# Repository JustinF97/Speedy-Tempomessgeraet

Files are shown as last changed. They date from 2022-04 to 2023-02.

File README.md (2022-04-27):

# Speedy-Tempomessgerät

[Justin Frommberger](https://github.com/JustinF97)

[Jonas Gerken](https://github.com/JonasGerken)

| Aufgabe | Link | 
| --- | --- |
| Projekt |[Link](https://github.com/)|  
| Ausarbeitung  |[Link](https://github.com/)|

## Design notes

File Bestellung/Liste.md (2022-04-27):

Material            | Name                        |Menge          | ❌ ✅
-----------         | ----------                  | ---------     | -------
Arduino             | Arduino Uno                 | 1x            |  ❌ 
Widerstände         | 220 & 60 Ohm                | 1x            |  ❌
RGB LED-Streifen    | WS2812B (60 LEDs/Meter)     | Ca. 5 Meter   |  ❌
Spannungsversorgung | Steckernetzteil  5V, 3A     | 1x            |  ❌
Gehäuse             | MDF-Platten 100/70/? Cm     | 3x            |  ❌
Kabel               | 0,5 / 0,75mm^2              | 3 Meter       |  ❌

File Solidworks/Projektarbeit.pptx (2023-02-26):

## Projektarbeit Speedy-Tempomessgerät

Von Jonas gerken und Justin Frommberger

## Thema

- Geschwindigkeit Messung von Autos
- Sicherheit von Personen
- Warnung bei zu schnellem fahren

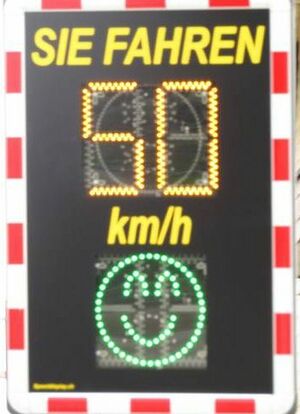
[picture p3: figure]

## Aufgabenstellung

- Ein System entwerfen
- Materialbeschaffung
- Zusammenbau des Projektes
- Anforderungen erfüllen
- Dokumentation
- Präsentation

## Anforderungen

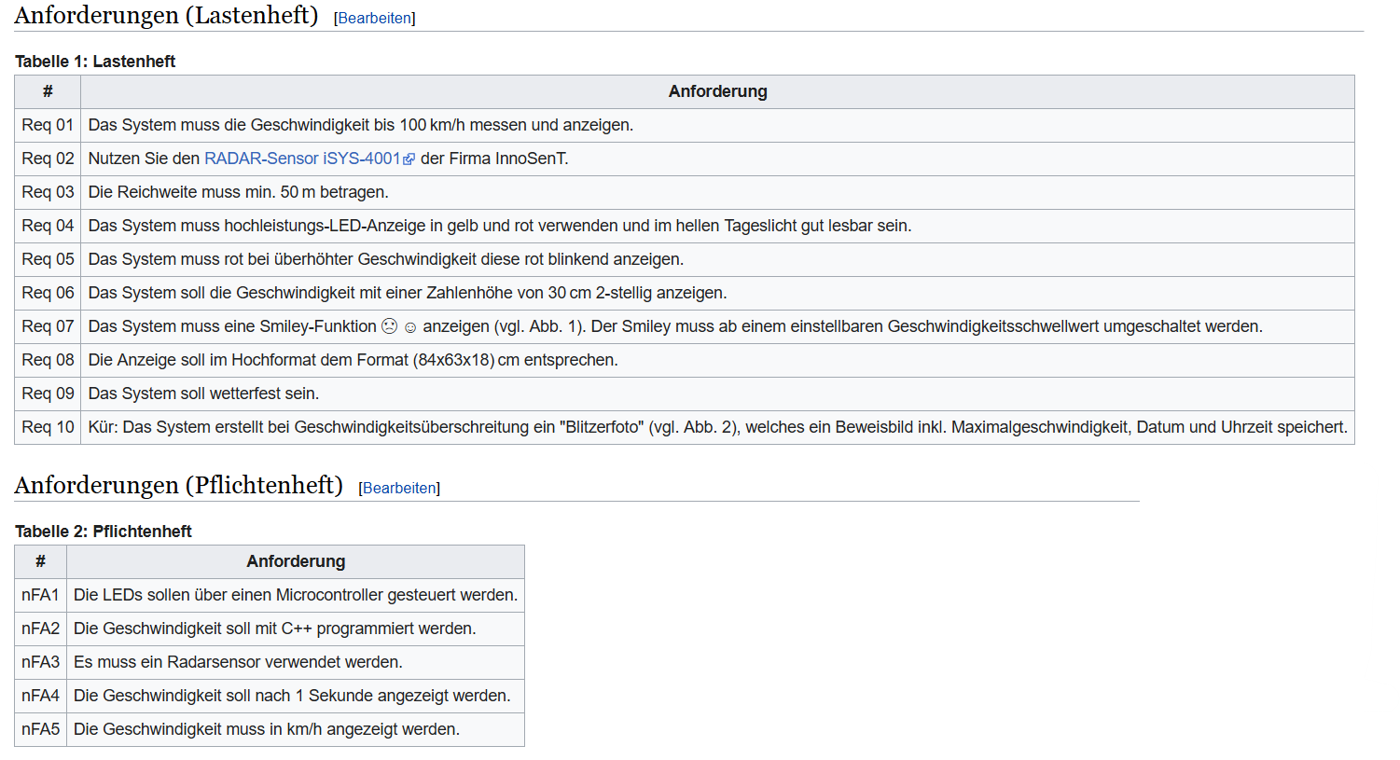
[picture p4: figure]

## Projektplan

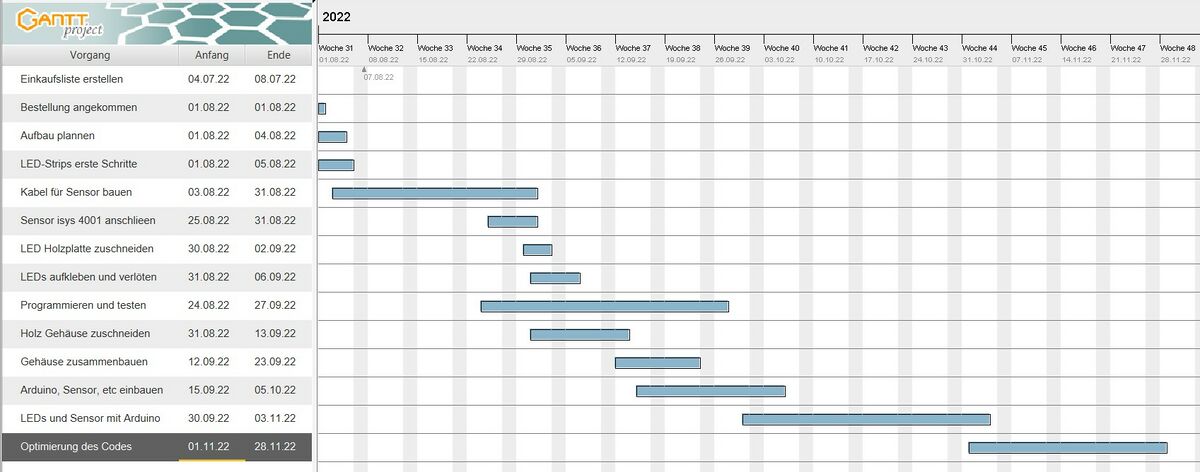
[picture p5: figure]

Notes: Jonas

## BOM (Bill of material)

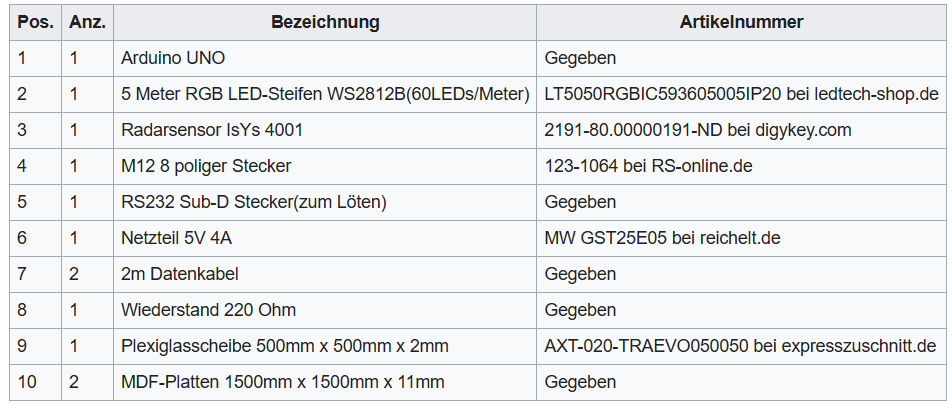
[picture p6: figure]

## Systementwurf

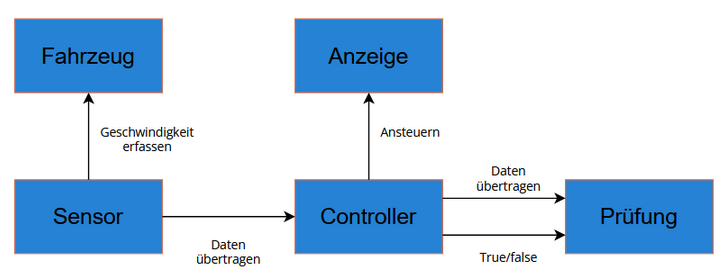
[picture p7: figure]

## Zeichnungsentwurf

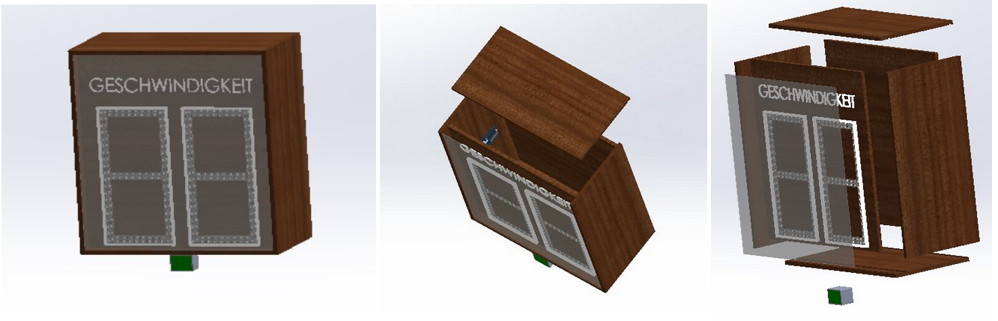
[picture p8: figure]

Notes: Jonas

## Elektronik

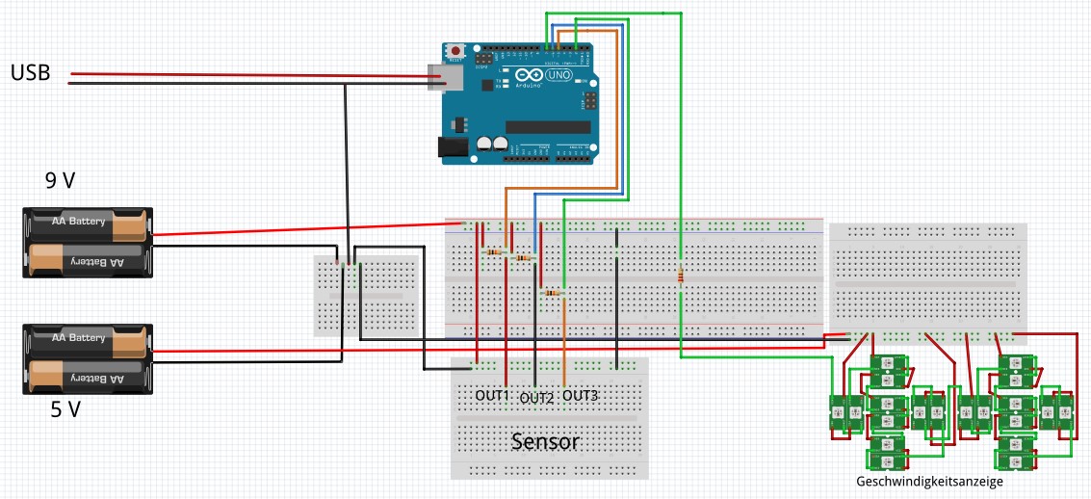
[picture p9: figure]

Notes: Jonas

## LED-Anzeige

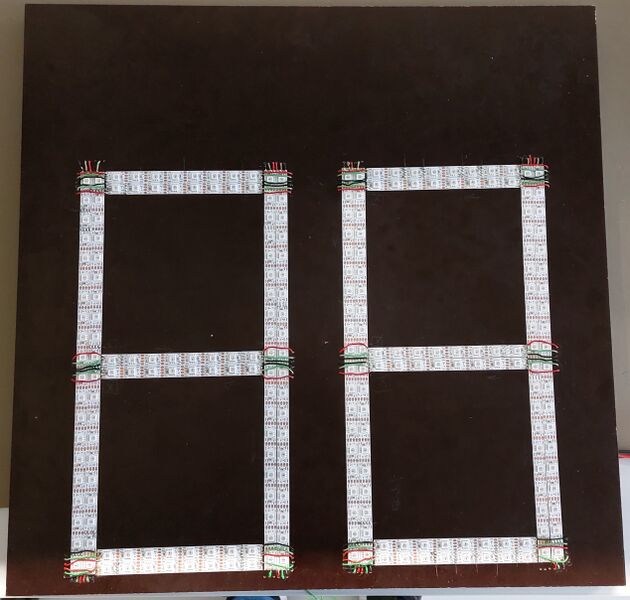
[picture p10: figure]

## Sensor GUI

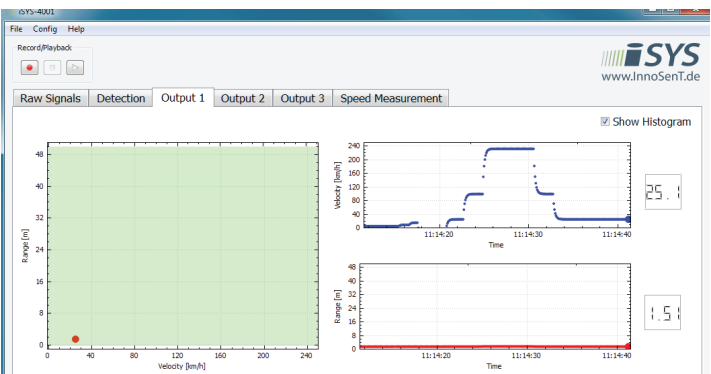
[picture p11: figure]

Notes: Jonas

## Sensor GUI Einstellungen

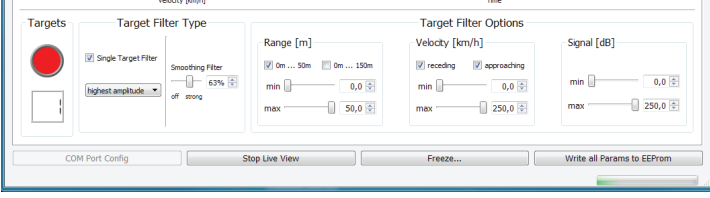
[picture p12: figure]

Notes: Jonas

## Output Konfiguration

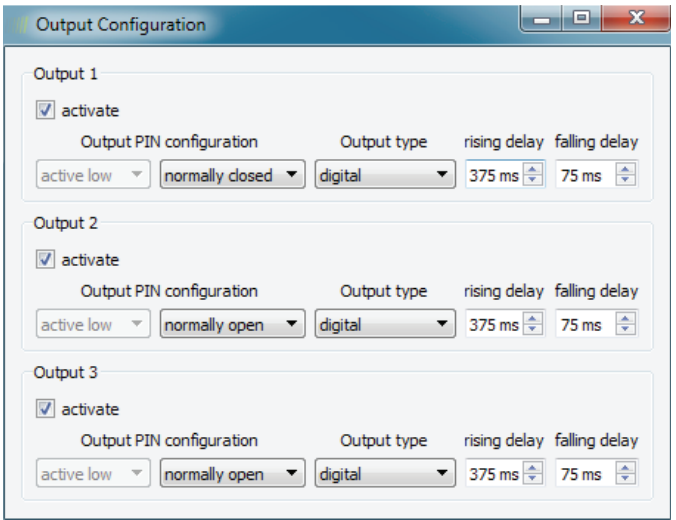
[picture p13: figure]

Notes: Jonas

## PWM

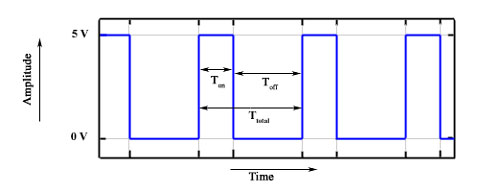
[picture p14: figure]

## Programmierung (Farbe)

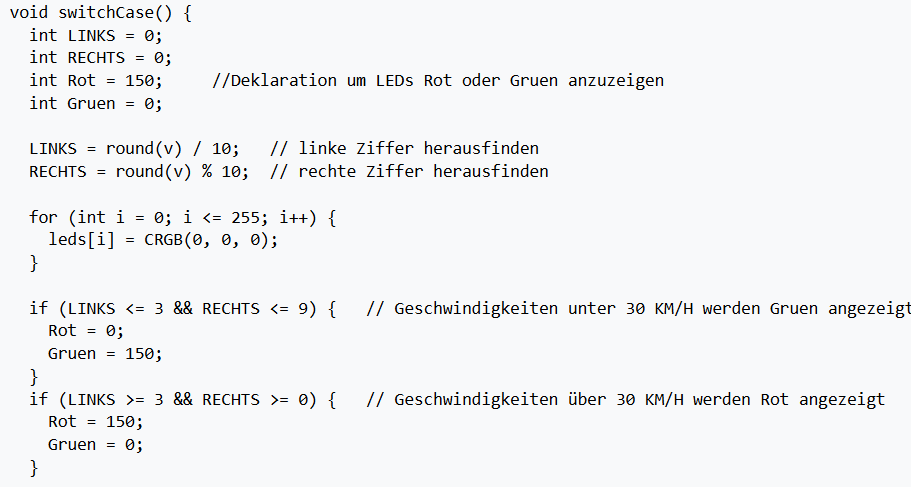
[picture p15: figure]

## Programmierung (Zahlen)

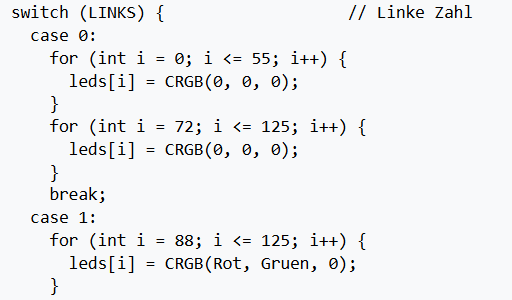
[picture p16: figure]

## Programmierung (Sensor)

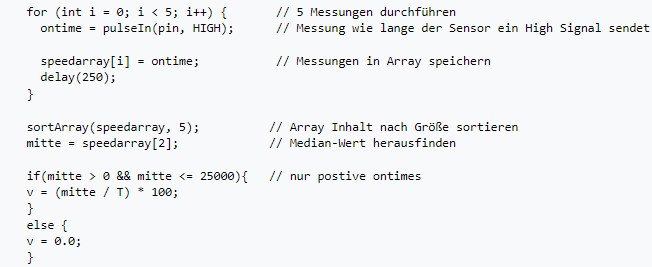
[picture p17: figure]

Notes: Jonas

## Live Präsentation

## Zusammenfassung

- Folgende Kompetenzen wurden erlernt:
- Projektplanung und Zeitmanagement
- CAD Konstruktion für 3D Druck
- 3D Druck
- Löten
- Ansteuerung von WS2812 LEDs
- Bau eines Kabels

## Ergebnis

- - Smiley Gesicht nicht eingebaut
- - Km/h nicht auf dem Schild beschriftet
- - Kleineres Gehäuse
- - Sensor funktioniert nicht einwandfrei
+ LED‘s zeigen die gewünschte Zahl an
+ Gehäuse ist stabil und transportabel
+ Autos können erfasst werden
+ Geschwindigkeit wird zur Anzeige übertragen

## Ausblick

- Smiley integrieren
- Sensor optimieren
- System durch Kamera erweitern

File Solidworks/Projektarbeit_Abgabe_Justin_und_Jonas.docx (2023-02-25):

Sommersemester 2022-
Wintersemester 2022/23

Praxissemester:

01.08.22 – 28.02.2023

Hochschule Hamm-Lippstadt

Praxissemester

Betreuer/in: Prof. Schneider

- Projektarbeit-

Einleitung

Der Schulweg von Kindern ist nicht sehr sicher. Durch Geschwindigkeitsmessungen des ADAC vor 25 Schulen in zehn Bundesländern wurden häufig Fahrer mit zu hohen Geschwindigkeiten gemessen. Die zulässige Höchstgeschwindigkeit von 30 km/h wurde von mehr als 60 Prozent der Autofahrer überschritten. Von insgesamt 43 828 Messungen, waren 26 329 zu schnell unterwegs. Vor einer Grundschule in Hamburg wurde ein Rekordwert von 96 km/h bei vorgeschriebenen 30km/h gemessen.

Um die Autofahrer abzuschrecken, können sogenannte Tempomessgeräte helfen.
Diese messen die Geschwindigkeit und zeigen diese über eine Anzeige dem vorbeifahrenden Fahrer. Zudem wird oft auch noch mit einem Smiley signalisiert, ob der Fahrer zu schnell fährt oder ob er sich an die vorgegebene Geschwindigkeit hält.

Aufgabenstellung

Die Aufgabe des Projektes war es, ein solches Tempomessgerät mit einem Radarsensor und einer LED-Anzeige, welche die Geschwindigkeit in km/h anzeigt, zu entwickeln.

Anforderungen







Projektplan (Justin Frommberger und Jonas Gerken)



BOM (Justin Frommberger und Jonas Gerken)

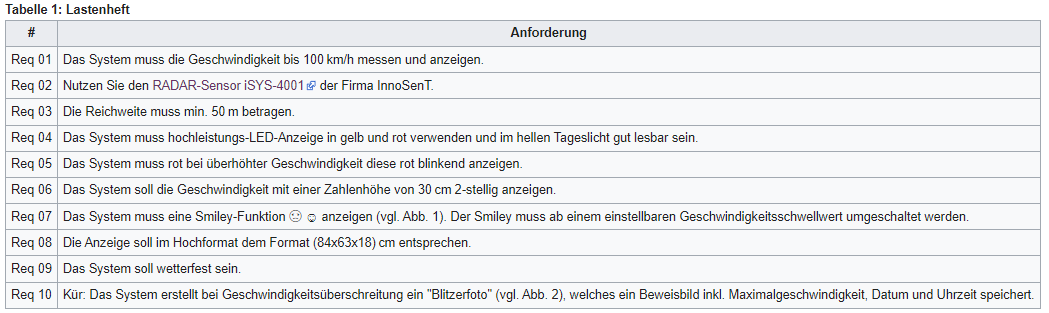
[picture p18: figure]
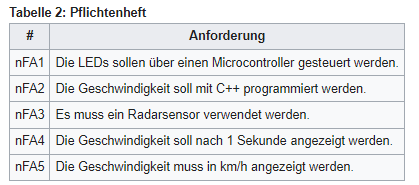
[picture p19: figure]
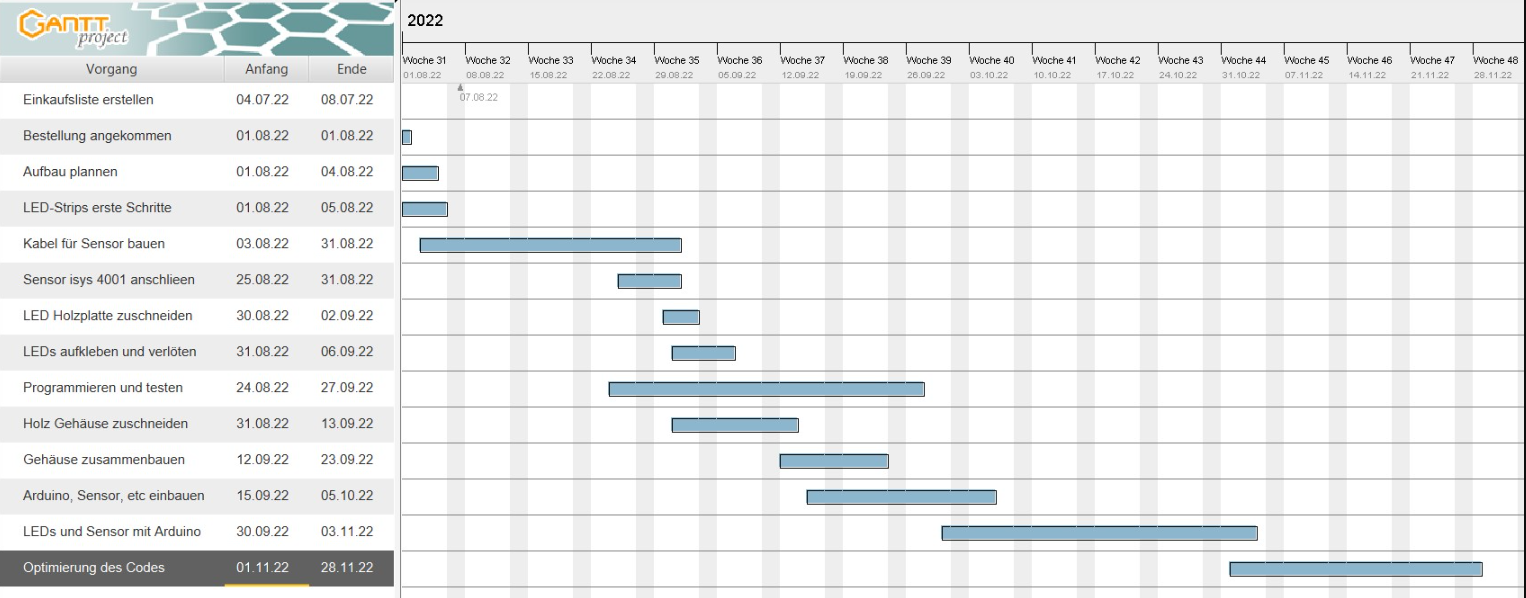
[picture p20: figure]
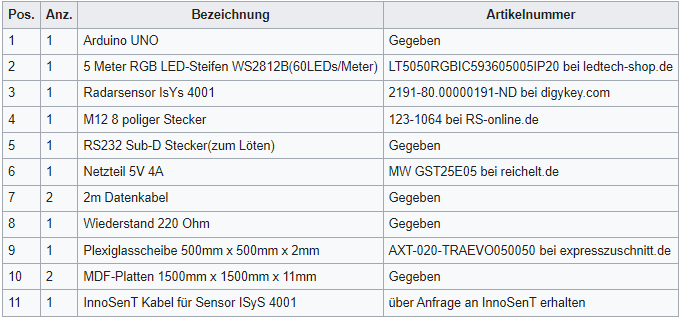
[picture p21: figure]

Funktionaler Systementwurf (Justin Frommberger)

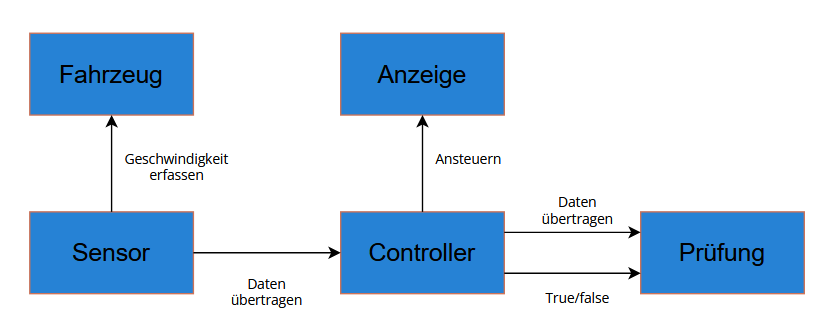
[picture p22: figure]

Abb. 1 Funktionaler Systementwurf

In Abb. 1 wird gezeigt, wie die Komponenten verbunden sind.
Der Sensor erfasst die Geschwindigkeit des Fahrzeugs und übergibt diese dem Microcontroller. Mit dem Mikrocontroller werden die Daten berechnet, die er vom Sensor empfängt. Die berechneten Werten werden dann auf der Segmentanzeige dargestellt.

Technischer Systementwurf (Jonas Gerken)


Abb. 2 Technischer Systementwurf

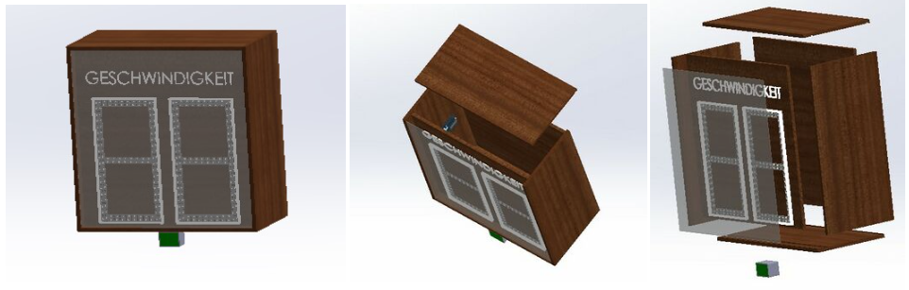
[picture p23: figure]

Die Abbildung 2 zeigt den technischen Systementwurf des Tempomessgerätes als CAD-Modell.

Radarsensor Isys 4001 (Jonas Gerken)

Der Kabelanschluss ist in Abb. 3 grafisch dargestellt.

Dargestellt ist der Female 8-polige Stecker, der mit dem Geschwindigkeitssensor verbunden wird. Das andere Ende des Kabels wird aufgeteilt in eine RS232-Schnittstelle und einem Stecker zur Verbindung mit dem Mikrocontroller der auch die Spannungsversorgung für den Sensor bereitstellt. Die RS232-Schnittstelle wird mit dem Computer verbunden zur Übertragung der Daten.

Abb. 3: Sensoranschluss

Um das Kabel anzuschließen, werden zwei Datenkabel mit Abschirmung benötigt. Das Kabel muss eine Abschirmung haben, um Störsignale zu vermeiden.

Für den RS232-Connector muss ein Kabel an einen Sub-D Stecke mit lötkontakten gelötet werden (Tabelle 1).

Wichtig ist es, die einzelnen Adern mit einem kleinen Schrumpfschlauch zu versehen, damit die Aderisolierung beim Löten nicht beschädigt wird. Das zweite Kabel ist für die Ausgänge Out1, Out2, Out3, genauso wie die Stromversorgung und der Ground.

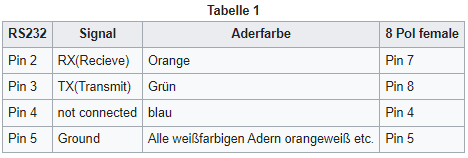
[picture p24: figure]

Für das zweite Kabel, welches für die Datenoutputs und die Stromversorgung verwendet wird, sieht die Pin-Belegungen wie folgt aus. (Tabelle 2)



Da der Sensor mit dem selbst gebauten Kabel nach mehreren Überprüfungen der Verbindungen nicht mit dem GUI-Programm verbunden werden konnte, wurde ein Kabel von der Firma InnoSenT angefragt. Mit diesem Kabel war es dann möglich, den Sensor mit dem GUI zu verbinden und zu konfigurieren.

Sensormessung

Damit ein PWM-Signal vom Sensor gesendet wird, muss zunächst ein Pull-up Widerstand (10kOHM) wie in Abb. 4 gezeigt, zwischen den Outputs geschaltet werden. Bei dem Anschluss an den Arduino muss beachtet werden, dass die Ausgänge OUT 1-3 an die PWM-Schnittstellen angeschlossen werden.


Abb. 4 OUT-Anschlüsse/Verkabelung

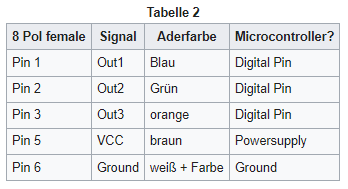
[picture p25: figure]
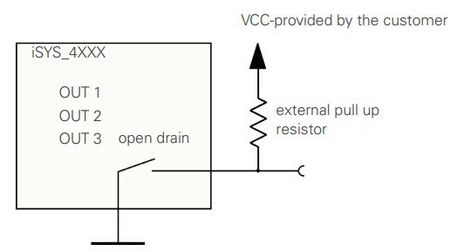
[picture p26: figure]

Das Signal kann nach der Verkabelung über ein Oszilloskop angezeigt werden. (Abb. 5)
Das obere PWM-Signal ist die Entfernung und das untere die Geschwindigkeit.


Abb. 5 PWM-Signal


Der Sensor sendet die PWM-Werte an den Arduino. Mit dem Arduino Befehl pulseIn(pin, HIGH), kann das Signal ausgelesen werden.

Mit den folgenden Formeln (Abb. 6) wird aus einer abgelesenen Geschwindigkeit das DC und folgend das „Ton“ berechnet.
Der Sensor sendet Ton-Werte an den Arduino und dieser muss in eine Geschwindigkeit umgerechnet werden.
Dazu muss die obere Formel nach km/h umgestellt werden und die untere Formel nach DC.
Rechts sind die umgestellten Formeln aufgezeigt, um die Geschwindigkeit zu berechnen.

DC=(6,275)/25⋅100

v=(25*100)/100 Abb. 6 Duty Cycle Formel

LED-Seven-Segment Aufbau und Verlötung (Justin Frommberger)

Der Erste Schritt ist, für die LED-Seven-Segmente eine Holzplatte auf 500 mm x 500 mm zuzuschneiden.
Auf dieser Holzplatte werden dann die LED-Stripes aufgeklebt.

Wir haben uns für die Seven-Segmente anzeige entschieden.

Diese LED-Strips haben wir doppelt nebeneinander geklebt, damit die angezeigte Geschwindigkeit später auf der Straße besser zu lesen ist.

Dazu wurden 8 Strips von einer Länge von 20 LEDs und 12 Strips von einer Länge von 8 LEDs zugeschnitten und angeklebt.


Abb. 7 LEDs auf Holzplatte

Beim Aufkleben ist es wichtig, die LEDs richtig herum aufzukleben.

Drauf geachtet werden muss, dass man mit der Kennzeichnung Strips "Di" für Digital In beginnen muss.

Der erste Strip wurde von oben nach unten geklebt, der Stripe rechts daneben von unten nach oben um die Reihenfolge einzuhalten.

So müssen unten später nur 3 kurze Kabel angelötet werden.

Von links außen und rechts außen wurden 50 mm und von dem unteren Rand wurden 15 mm Platz bis zu den LED-Stripes gelassen.

Abb. 7 zeigt die fertige Segmentanzeige.


Abb. 8: Verkabelung

Bei einer so großen Anzahl an LEDs ist es notwendig, die LEDs an mehreren Stellen mit der Stromquelle zu verbinden.

Dazu wurden, wie in Abb. 8 zusehen ist ein rotes und ein schwarzes 4 mm² Kabel an eine Europlatine gelötet, welche dann die Hauptstromversorgung darstellt.

Die Seven-Segmentanzeige wurde dafür jeweils in drei Abschnitte unterteilt.
Das Seven Segment wurde wie folgt aufgeteilt:
- die linken senkrechten LEDs
- die rechten senkrechten LEDs
- die waagerechten LEDs


Auf der Holzplatte wurden an jeder Ecke 3 Löcher gebohrt, um die Kabel zur Rückseite durchzuführen und dort zu verdrahten.

Für die Verbindungen zwischen den Strips, wurde ein 0,5 mm² Kabel in zwei verschiedenen Farben: Rot (Strom), Schwarz (Erde), Grün (Daten) zugeschnitten und verlötet.

Das Datenkabel wird nicht in Reihen aufgeteilt, denn alle LEDs müssen zur Programmierung in Reihe angeschlossen werden. So kann später mit Variablen jede einzelne LED angesteuert werden.

Die Abschnitte werden jeweils an die Europlatine angelötet, wie auf dem Bild zu sehen ist. (Abb. 8)

LED Dimmung (Jonas Gerken)

Um die Autofahrer mit den LED‘s nicht zu blenden, haben wir uns überlegt, eine Abdeckung mit dem 3D-Drucker zu entwerfen um das Licht zu dimmen. Die einzelnen Bauteile für die Abdeckung wurden mit SolidWorks gezeichnet und in eine STL Datei umgewandelt. Die Einzelteile die mit dem 3D-Drucker gedruckt wurden, haben wir anschließend auf die Holzplatte über die LED‘s festgeklebt.

In Abb. 9 ist dann das Ergebnis der fertigen Abdeckung zusehen.


Abb. 9 LED-Abdeckung


Gehäuse (Justin Frommberger)

Für das Gehäuse wurden drei 11 mm dicke Holzplatten auf 250 mm * 500 mm zugeschnitten. Eine von den Holzplatten wird mit drei Nuten versehen, die Nuten sind zur befestigen der LED-Platte, der Plexiglasscheibe und der Rückwand.


Mit der zweiten und dritten Platte wird die Außenwand befestigt. Die Platte für die Rückwand wird aus einer 11 mm dicken Holzplatte auf 500 mm * 500 mm zugeschnitten. Zudem muss auch die Plexiglasscheibe auf 500 mm * 500 mm zugeschnitten werden, um in die dafür vorgesehene Halterung zu passen. Am Ende schnitten wir die letzte Platte auf 500 mm * 500 mm und klebten auf diese Platte, die 7 Segment LED Pixelstreifen.

Wir montierten alle Teile des Gehäuses zusammen und befestigten diese zusätzlich mit Schrauben für einen besseren Halt.

Der fertige Aufbau ist in Abb. 10 zusehen.


Abb. 10 Gehäuse


Elektronik (Jonas Gerken)

Die Abb. 11 zeigt die Elektrische Schaltung.


Abb. 11: Schaltung


Stromquellen:

- Radarsensor: 5 bis 30 Volt (in Abb. 7 links)
- LED-Geschwindigkeitsanzeige: 5 Volt (in Abb. 7 rechts)

Arduino Uno:

- Digital Pin 3, 5, 6: OUT1, OUT2, OUT3 des Radarsensors
- Digital Pin 7: Digital der Geschwindigkeitsanzeige

Radarsensor:

- OUT1, OUT2, und OUT3 mit einem PULL-UP Widerstand verbunden

LED-Geschwindigkeitsanzeige:

- Senkrechten LED-Streifen jeweils links und rechts mit der Stromquelle verbunden
- die mittleren LED-Streifen jeweils links und rechts mit der Stromquelle verbunden

Programmierung

Farbe der LEDs (Justin Frommberger)

Abb. 12 LED-Programmierung (Farbe)


Zahlen Anzeige (Justin Frommberger)


Abb. 13 Zahlen Anzeige


Um die Zahlen auf dem Display anzuzeigen, wurde ein Switch Case programmiert, um die benötigten LEDs einzuschalten. Wie im Beispiel Case 0, werden alle LEDS von 0 bis 55 und von 72 bis 125 eingeschaltet.


Sensor (Jonas Gerken)

Abb. 14 Sensor Programmierung


Ergebnis (Justin Frommberger und Jonas Gerken)

Fast alle Anforderungen des Projektes konnten erfüllt werden. Wir unterschätzten, dass die LED‘s eine Menge an Strom benötigen (aktueller Stand 10A), so mussten wir bei unserem Projekt LED‘s einsparen und beschlossen das Smiley Gesicht nicht einzubauen.

Um trotzdem die gewünschte Aufgabe zu erfüllen, überlegten wir uns, dass wir die nicht überschrittene Geschwindigkeit Grün anzeigen lassen.

Die zu hohe Geschwindigkeit stellen wir in roter Farbe dar. Zudem haben wir uns für ein kleineres Format des Schildes entschieden, um unser Projekt besser transportieren zu können. Auch haben wir uns gegen einen Schriftzug vom km/h entschieden, um die Zahlen möglichst groß und sichtbar für die Fahrer zu gestalten. Leider haben wir festgestellt, dass der vorhandene Radarsensor Isys 4001 eine Störung hat und keine konstanten Werte zurückliefert, dieses führt bei der Anzeige zu ungenauen Werten.

Alle anderen oben aufgelisteten Anforderungen konnten wir erfüllen.

Zusammenfassung (Justin Frommberger und Jonas Gerken)

Lessons learned

Das Team hat die folgenden Kompetenzen erlernt:

- Projektplanung und Zeitmanagement
- CAD-Konstruktion für 3D Druck
- 3D Druck
- Löten
- Ansteuerung von WS2812 LEDs
- Bau eines Kabels

Besondere Herausforderungen

Die erste Herausforderung bei unserem Projekt „Speed-Tempomessgerät“, stellte sich direkt am Anfang bei der Materialbeschaffung. Das Problem war es, das alle Materialien, die für das Projekt benötigt werden zu beschaffen. Wir stellten fest, dass bei dem vorhandenen Radarsensor der Hochschule das Kabel zur Strom- und Datenversorgung fehlte. Weil das Kabel kein Standardkabel war, informierten wir uns bei dem Hersteller des Sensors wie das Kabel aufgebaut ist und ließen uns das dazugehörige Datenblatt schicken. Um das Kabel selbst anzufertigen, bestellten wir dafür einen RS232 Sub-D Stecker und einen M12 8 poligen Stecker. Das Herstellen des Kabels konnte nach langem ausprobieren und telefonischem Austausch mit der Herstellerfirma nicht abgeschlossen werden. Folgend fragten wir die Firma, ob sie uns ein Kabel zuschicken könnten. Freundlicherweise ließen sie uns ein Kabel kostenlos zukommen, um unser Problem zu lösen.

Die nächste Herausforderung war es, herauszufinden, wie groß die Netzteile seien müssen, um unser komplettes Projekt mit Strom zu versorgen. So recherchierten wir in den Datenblättern des Sensors und der RGBs, wie groß die Netzteile sein müssen. Später stellte sich heraus beim Anschließen der RGB-Kette, dass die LED‘s viel mehr Strom in Reihenschaltung benötigten als wir berechnet hatten (über 20A). Folgend beschlossen wir unsere Schaltung um zulöten, wir setzten die Stromversorgung mittig und teilten diese in 4 Reihenschaltungen auf. Wir verringerten den benötigten Stromverbrauch auf ungefähr 10A. Zusätzlich verzichteten wir auf weitere RGBs für das Smiley, um Strom zu sparen und ein transportables Netzteil nutzen zu können.

Eine weitere Herausforderung im Projekt war die Ansteuerung der einzelnen RBGs, da diese teilweise zusammengeschaltet sind und beim Ansteuern einer RBG zwei Stück eingeschaltet werden. Nach mehrfachen neu Löten konnte der Fehler nicht gefunden werden.

Daraufhin haben wir uns eine neue Schaltung (Abb.8) entwickelt, mit der wir unsere Schaltung umsetzen konnten.

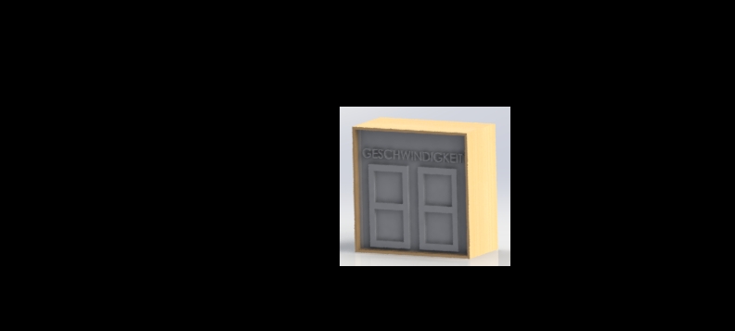
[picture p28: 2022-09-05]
Solidworks/Solidworks_Projektarbeit/Bilder/Tempomessgerät_Schild.JPG

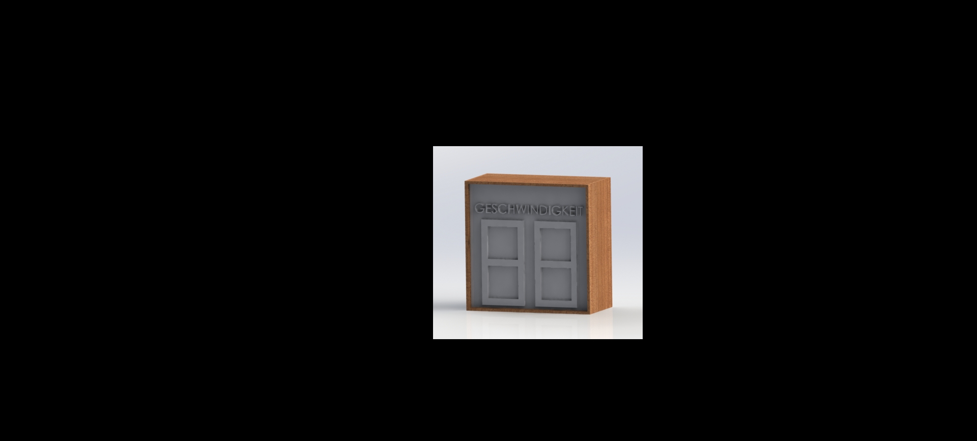
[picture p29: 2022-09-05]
Solidworks/Solidworks_Projektarbeit/Bilder/Rendering Schild2.JPG

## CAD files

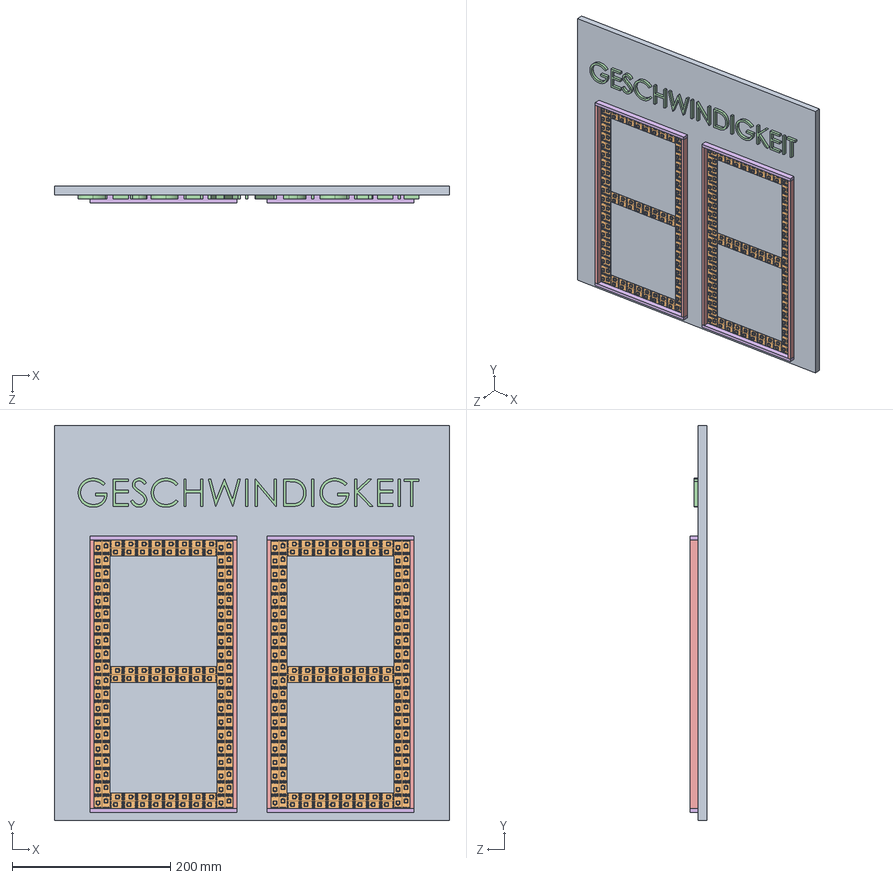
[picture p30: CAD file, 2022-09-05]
Solidworks/Solidworks_Projektarbeit/LED_Platte_Baugruppe.SLDASM
500.0 x 500.0 x 21.0 mm
LED-PLatte 2
LED-Strip x 256
Kumpferplätchen x 2048
SchildSchrift
Lichtschirmlang x 4
Schirmmittellang x 4

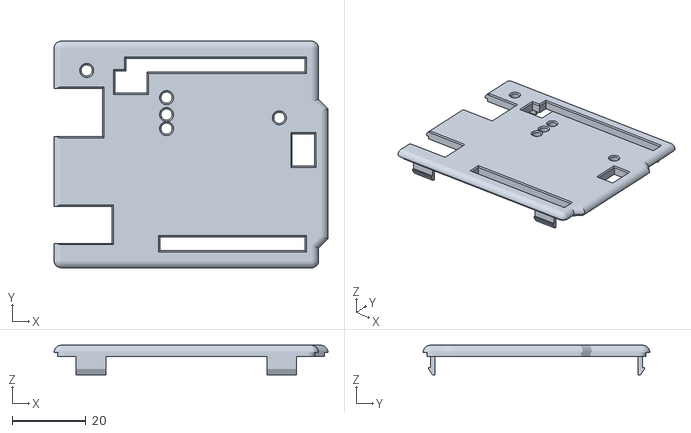
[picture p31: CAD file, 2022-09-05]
Solidworks/Solidworks_Projektarbeit/arduino-uno-case-3d-printed-1.snapshot.5/arduino_uno_top.stl
74.1 x 61.3 x 8.00

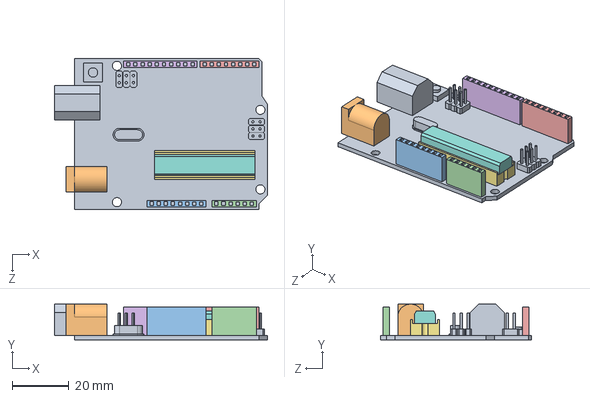
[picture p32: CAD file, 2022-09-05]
Solidworks/Solidworks_Projektarbeit/arduino-uno-case-3d-printed-1.snapshot.5/uno.STEP
75.0 x 12.6 x 53.0 mm

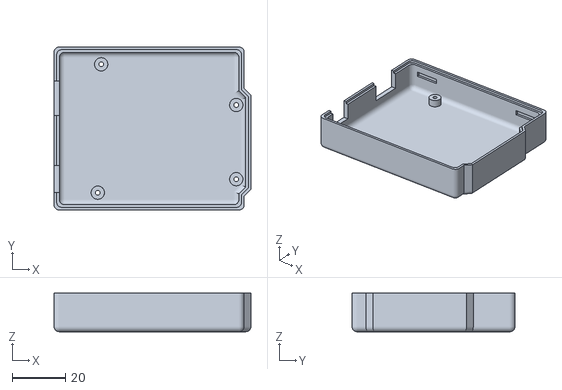
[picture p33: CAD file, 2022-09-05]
Solidworks/Solidworks_Projektarbeit/arduino-uno-case-3d-printed-1.snapshot.5/arduino_uno_bottom.stl
74.1 x 61.3 x 14.5

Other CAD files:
Solidworks/Solidworks_Projektarbeit/Baugruppe_Projekt.SLDDRW
Solidworks/Solidworks_Projektarbeit/Kumpferplätchen.SLDPRT
Solidworks/Solidworks_Projektarbeit/LED-Strip.SLDPRT
Solidworks/Solidworks_Projektarbeit/PlexiScheibeFront.SLDPRT
Solidworks/Solidworks_Projektarbeit/Rückwand.SLDPRT
Solidworks/Solidworks_Projektarbeit/SchildSchrift.SLDPRT
Solidworks/Solidworks_Projektarbeit/Schirmmittellang.SLDPRT
Solidworks/Solidworks_Projektarbeit/SeitenAußen72cm.SLDPRT
Solidworks/Solidworks_Projektarbeit/Zeichnung_Projekt.SLDDRW
Solidworks/Solidworks_Projektarbeit/arduino-uno-case-3d-printed-1.snapshot.5/uno.SLDPRT

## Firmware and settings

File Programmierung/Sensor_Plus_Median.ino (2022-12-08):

#include <FastLED.h>

#include "MedianFilterLib2.h"

#define LED_PIN 7
#define NUM_LEDS 257

CRGB leds[NUM_LEDS];

int DELAYVAL = 400;
int median = 0;


int v, vmax, ontime, offtime;
int pin = 3;
int max = 0;
int speedarray[] = {1, 1, 2, 7, 5, 9, 2, 5, 4, 2};
size_t valuesLength = sizeof(speedarray) / sizeof(speedarray[0]);

int getMeasure() {
  size_t static index = 0;
  index++;
  //unsigned long T;  // Periodendauer in us
  //int f;            // Frequenz in MHz
  //vmax = 0;         //

 // for (int i = 0; i <= 9; i++) {

 //   ontime = pulseIn(pin, HIGH);
  //  offtime = pulseIn(pin, LOW);
  //  T = ontime + offtime;
  //  f = 1000000 / T;  // f=1/T
  //  v = f / 44.0;     // 24 GHz Radar
    //speedarray[i] = v;
 // }
  return speedarray[index - 1];

}

MedianFilter2<int> medianFilter(5);

void setup() {
  FastLED.addLeds<WS2812B, LED_PIN, GRB>(leds, NUM_LEDS);
  Serial.begin(115200);
  pinMode(pin, INPUT);
}

void loop() {
  int rawMeasure = getMeasure();

  float timeMean = 0;
  for (size_t iCount = 0; iCount < valuesLength; iCount++) {

    unsigned long timeCount = micros();
    int median = medianFilter.AddValue(rawMeasure);
    timeCount = micros() - timeCount;
    timeMean += timeCount;
    Serial.print("Wert = ");
    Serial.print(median);
  }
  // LED ausführen
  switchCase();
  FastLED.show();
  delay(DELAYVAL);
}

void switchCase() {
  int LINKS = 0;
  int RECHTS = 0;
  int Rot = 150;
  int Gruen = 0;

  LINKS = median / 10;
  RECHTS = median % 10;

  for (int i = 0; i <= 255; i++) {
    leds[i] = CRGB(0, 0, 0);
  }

  if (LINKS <= 3 && RECHTS <= 9) {
    Rot = 0;
    Gruen = 150;
  }
  if (LINKS >= 3 && RECHTS >= 0) {
    Rot = 150;
    Gruen = 0;
  }

  switch (LINKS) {
    case 0:
      for (int i = 0; i <= 55; i++) {
        leds[i] = CRGB(0, 0, 0);
      }
      for (int i = 72; i <= 125; i++) {
        leds[i] = CRGB(0, 0, 0);
      }
      break;
    case 1:
      for (int i = 88; i <= 125; i++) {
        leds[i] = CRGB(Rot, Gruen, 0);
      }
      break;
    case 2:
      for (int i = 10; i <= 29; i++) {
        leds[i] = CRGB(Rot, Gruen, 0);
      }
      for (int i = 40; i <= 86; i++) {
        leds[i] = CRGB(Rot, Gruen, 0);
      }
      for (int i = 97; i <= 115; i++) {
        leds[i] = CRGB(Rot, Gruen, 0);
      }
      break;
    case 3:
      for (int i = 40; i <= 86; i++) {
        leds[i] = CRGB(Rot, Gruen, 0);
      }
      for (int i = 87; i <= 125; i++) {
        leds[i] = CRGB(Rot, Gruen, 0);
      }
      break;
    case 4:
      for (int i = 0; i <= 9; i++) {
        leds[i] = CRGB(Rot, Gruen, 0);
      }
      for (int i = 30; i <= 39; i++) {
        leds[i] = CRGB(Rot, Gruen, 0);
      }
      for (int i = 56; i <= 71; i++) {
        leds[i] = CRGB(Rot, Gruen, 0);
      }
      for (int i = 88; i <= 125; i++) {
        leds[i] = CRGB(Rot, Gruen, 0);
      }
      break;
    case 5:
      for (int i = 0; i <= 9; i++) {
        leds[i] = CRGB(Rot, Gruen, 0);
      }
      for (int i = 30; i <= 87; i++) {
        leds[i] = CRGB(Rot, Gruen, 0);
      }
      for (int i = 88; i <= 96; i++) {
        leds[i] = CRGB(Rot, Gruen, 0);
      }
      for (int i = 116; i <= 125; i++) {
        leds[i] = CRGB(Rot, Gruen, 0);
      }
      break;
    case 6:
      for (int i = 0; i <= 96; i++) {
        leds[i] = CRGB(Rot, Gruen, 0);
      }
      for (int i = 116; i <= 125; i++) {
        leds[i] = CRGB(Rot, Gruen, 0);
      }
      break;
    case 7:
      for (int i = 40; i <= 55; i++) {
        leds[i] = CRGB(Rot, Gruen, 0);
      }
      for (int i = 88; i <= 125; i++) {
        leds[i] = CRGB(Rot, Gruen, 0);
      }
      break;
    case 8:
      for (int i = 0; i <= 125; i++) {
        leds[i] = CRGB(Rot, Gruen, 0);
      }
      break;
    case 9:
      for (int i = 0; i <= 9; i++) {
        leds[i] = CRGB(Rot, Gruen, 0);
      }
      for (int i = 30; i <= 39; i++) {
        leds[i] = CRGB(Rot, Gruen, 0);
      }
      for (int i = 40; i <= 125; i++) {
        leds[i] = CRGB(Rot, Gruen, 0);
      }
      break;
  }


  switch (RECHTS) {
    case 0:
      for (int i = 127; i <= 182; i++) {
        leds[i] = CRGB(Rot, Gruen, 0);
      }
      for (int i = 199; i <= 254; i++) {
        leds[i] = CRGB(Rot, Gruen, 0);
      }
      break;
    case 1:
      for (int i = 215; i <= 254; i++) {
        leds[i] = CRGB(Rot, Gruen, 0);
      }
      break;
    case 2:
      for (int i = 137; i <= 156; i++) {
        leds[i] = CRGB(Rot, Gruen, 0);
      }
      for (int i = 167; i <= 213; i++) {
        leds[i] = CRGB(Rot, Gruen, 0);
      }
      for (int i = 225; i <= 244; i++) {
        leds[i] = CRGB(Rot, Gruen, 0);
      }
      break;
    case 3:
      for (int i = 167; i <= 213; i++) {
        leds[i] = CRGB(Rot, Gruen, 0);
      }
      for (int i = 214; i <= 254; i++) {
        leds[i] = CRGB(Rot, Gruen, 0);
      }
      break;
    case 4:
      for (int i = 127; i <= 136; i++) {
        leds[i] = CRGB(Rot, Gruen, 0);
      }
      for (int i = 157; i <= 166; i++) {
        leds[i] = CRGB(Rot, Gruen, 0);
      }
      for (int i = 183; i <= 198; i++) {
        leds[i] = CRGB(Rot, Gruen, 0);
      }
      for (int i = 215; i <= 254; i++) {
        leds[i] = CRGB(Rot, Gruen, 0);
      }
      break;
    case 5:
      for (int i = 127; i <= 136; i++) {
        leds[i] = CRGB(Rot, Gruen, 0);
      }
      for (int i = 157; i <= 214; i++) {
        leds[i] = CRGB(Rot, Gruen, 0);
      }
      for (int i = 215; i <= 224; i++) {
        leds[i] = CRGB(Rot, Gruen, 0);
      }
      for (int i = 245; i <= 254; i++) {
        leds[i] = CRGB(Rot, Gruen, 0);
      }
      break;
    case 6:
      for (int i = 127; i <= 224; i++) {
        leds[i] = CRGB(Rot, Gruen, 0);
      }
      for (int i = 245; i <= 254; i++) {
        leds[i] = CRGB(Rot, Gruen, 0);
      }
      break;
    case 7:
      for (int i = 167; i <= 182; i++) {
        leds[i] = CRGB(Rot, Gruen, 0);
      }
      for (int i = 215; i <= 254; i++) {
        leds[i] = CRGB(Rot, Gruen, 0);
      }
      break;
    case 8:
      for (int i = 127; i <= 254; i++) {
        leds[i] = CRGB(Rot, Gruen, 0);
      }
      break;
    case 9:
      for (int i = 127; i <= 136; i++) {
        leds[i] = CRGB(Rot, Gruen, 0);
      }
      for (int i = 157; i <= 166; i++) {
        leds[i] = CRGB(Rot, Gruen, 0);
      }
      for (int i = 167; i <= 254; i++) {
        leds[i] = CRGB(Rot, Gruen, 0);
      }
      break;
  }
  delay(500);
  max = 0;
}

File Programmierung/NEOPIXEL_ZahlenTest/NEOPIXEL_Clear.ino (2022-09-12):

// NeoPixel Ring simple sketch (c) 2013 Shae Erisson
// Released under the GPLv3 license to match the rest of the
// Adafruit NeoPixel library

#include <Adafruit_NeoPixel.h>
#ifdef __AVR__
 #include <avr/power.h> // Required for 16 MHz Adafruit Trinket
#endif

// Which pin on the Arduino is connected to the NeoPixels?
#define PIN        7 // On Trinket or Gemma, suggest changing this to 1

// How many NeoPixels are attached to the Arduino?
#define NUMPIXELS 257 // Popular NeoPixel ring size

// When setting up the NeoPixel library, we tell it how many pixels,
// and which pin to use to send signals. Note that for older NeoPixel
// strips you might need to change the third parameter -- see the
// strandtest example for more information on possible values.
Adafruit_NeoPixel pixels(NUMPIXELS, PIN, NEO_GRB + NEO_KHZ800);

#define DELAYVAL 500 // Time (in milliseconds) to pause between pixels

void setup() {
  // These lines are specifically to support the Adafruit Trinket 5V 16 MHz.
  // Any other board, you can remove this part (but no harm leaving it):
#if defined(__AVR_ATtiny85__) && (F_CPU == 16000000)
  clock_prescale_set(clock_div_1);
#endif
  // END of Trinket-specific code.

  pixels.begin(); // INITIALIZE NeoPixel strip object (REQUIRED)

}

void loop() {
  pixels.clear(); // Set all pixel colors to 'off'

  // The first NeoPixel in a strand is #0, second is 1, all the way up
  // to the count of pixels minus one.
  LinksNull();
  RechtsFuenf();

}

void LinksNull(){
    //obenlinks
    for(int i=0; i<10; i++) { // For each pixel...
    // pixels.Color() takes RGB values, from 0,0,0 up to 255,255,255
    // Here we're using a moderately bright green color:
    pixels.setPixelColor(i, pixels.Color(0, 255, 0));
    for(int j=30; j<40; j++){
      pixels.setPixelColor(j, pixels.Color(0, 255, 0));
    }
   // delay(DELAYVAL); // Pause before next pass through loop
 }
    //untenlinks
    for(int i=10; i<20; i++) { // For each pixel...
    // pixels.Color() takes RGB values, from 0,0,0 up to 255,255,255
    // Here we're using a moderately bright green color:
    pixels.setPixelColor(i, pixels.Color(0, 255, 0));
    for(int j=20; j<30; j++){
      pixels.setPixelColor(j, pixels.Color(0, 255, 0));
    }
   // delay(DELAYVAL); // Pause before next pass through loop
 }
    //obenrechts
    for(int i=98; i<108; i++) { // For each pixel...
    // pixels.Color() takes RGB values, from 0,0,0 up to 255,255,255
    // Here we're using a moderately bright green color:
    pixels.setPixelColor(i, pixels.Color(0, 255, 0));
    for(int j=108; j<118; j++){
      pixels.setPixelColor(j, pixels.Color(0, 255, 0));
    }
   // delay(DELAYVAL); // Pause before next pass through loop
 }
   //untenrechts
   for(int i=118; i<128; i++) { // For each pixel...

    // pixels.Color() takes RGB values, from 0,0,0 up to 255,255,255
    // Here we're using a moderately bright green color:
    pixels.setPixelColor(i, pixels.Color(0, 255, 0));
    for(int j=88; j<98; j++){
      pixels.setPixelColor(j, pixels.Color(0, 255, 0));
    }
   // delay(DELAYVAL); // Pause before next pass through loop 
 }
  //obenmitte
  for(int i=40; i<56; i++) { // For each pixel...

    // pixels.Color() takes RGB values, from 0,0,0 up to 255,255,255
    // Here we're using a moderately bright green color:
    pixels.setPixelColor(i, pixels.Color(0, 255, 0));
   // delay(DELAYVAL); // Pause before next pass through loop
  
 } 
   //untenmitte
   for(int i=72; i<88; i++) { // For each pixel...
    // pixels.Color() takes RGB values, from 0,0,0 up to 255,255,255
    // Here we're using a moderately bright green color:
    pixels.setPixelColor(i, pixels.Color(0, 255, 0));
   // delay(DELAYVAL); // Pause before next pass through loop
  
 }
  pixels.setBrightness(50);
  pixels.show();   // Send the updated pixel colors to the hardware.
       
}

void LinksFuenf(){
    //obenlinks
    for(int i=0; i<10; i++) { // For each pixel...
    // pixels.Color() takes RGB values, from 0,0,0 up to 255,255,255
    // Here we're using a moderately bright green color:
    pixels.setPixelColor(i, pixels.Color(0, 255, 0));
    for(int j=30; j<40; j++){
      pixels.setPixelColor(j, pixels.Color(0, 255, 0));
    }
   // delay(DELAYVAL); // Pause before next pass through loop
 }
  //obenmitte
  for(int i=40; i<56; i++) { // For each pixel...

    // pixels.Color() takes RGB values, from 0,0,0 up to 255,255,255
    // Here we're using a moderately bright green color:
    pixels.setPixelColor(i, pixels.Color(0, 255, 0));



   // delay(DELAYVAL); // Pause before next pass through loop
  
 }
   //mittemitte
   for(int i=56; i<72; i++) { // For each pixel...

    // pixels.Color() takes RGB values, from 0,0,0 up to 255,255,255
    // Here we're using a moderately bright green color:
     pixels.setPixelColor(i, pixels.Color(0, 255, 0));
   // delay(DELAYVAL); // Pause before next pass through loop
 }
   //untenrechts
   for(int i=118; i<128; i++) { // For each pixel...

    // pixels.Color() takes RGB values, from 0,0,0 up to 255,255,255
    // Here we're using a moderately bright green color:
    pixels.setPixelColor(i, pixels.Color(0, 255, 0));
    for(int j=88; j<98; j++){
      pixels.setPixelColor(j, pixels.Color(0, 255, 0));
    }
   // delay(DELAYVAL); // Pause before next pass through loop 
 }
   //untenmitte
   for(int i=72; i<88; i++) { // For each pixel...
    // pixels.Color() takes RGB values, from 0,0,0 up to 255,255,255
    // Here we're using a moderately bright green color:
    pixels.setPixelColor(i, pixels.Color(0, 255, 0));
   // delay(DELAYVAL); // Pause before next pass through loop
  
 }
 
  pixels.setBrightness(50);
  pixels.show();   // Send the updated pixel colors to the hardware.
}
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
